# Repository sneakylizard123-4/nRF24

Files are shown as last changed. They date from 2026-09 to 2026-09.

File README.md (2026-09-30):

# nRF24 Breakout Board

A small 2.4GHz module based on the nRF24L01P+, with an SMA jack for an external
antenna, an on-board RFX2401C PA/LNA for extra range, and a breadboard friendly
SPI header. Runs from 3.3V or 5V off an on-board LDO.

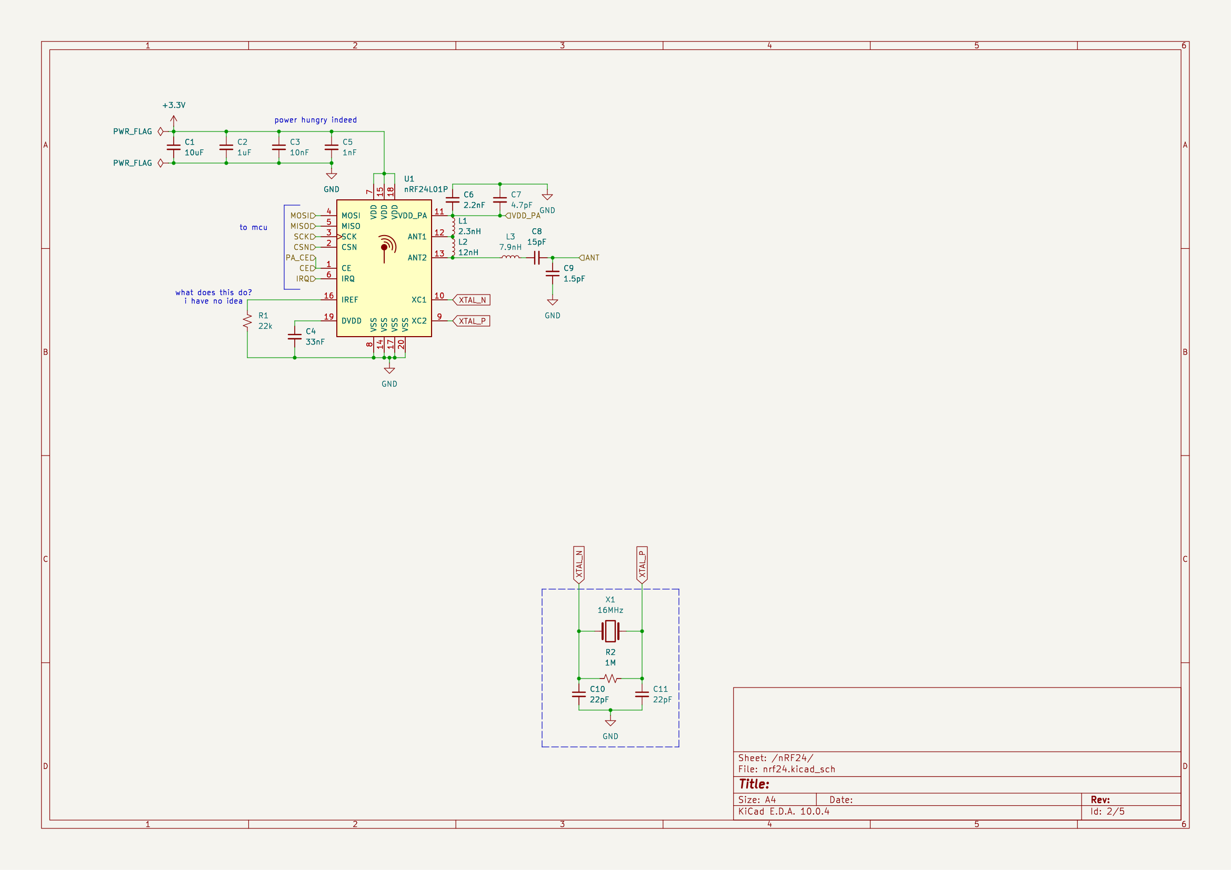
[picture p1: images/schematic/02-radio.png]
Radio sheet


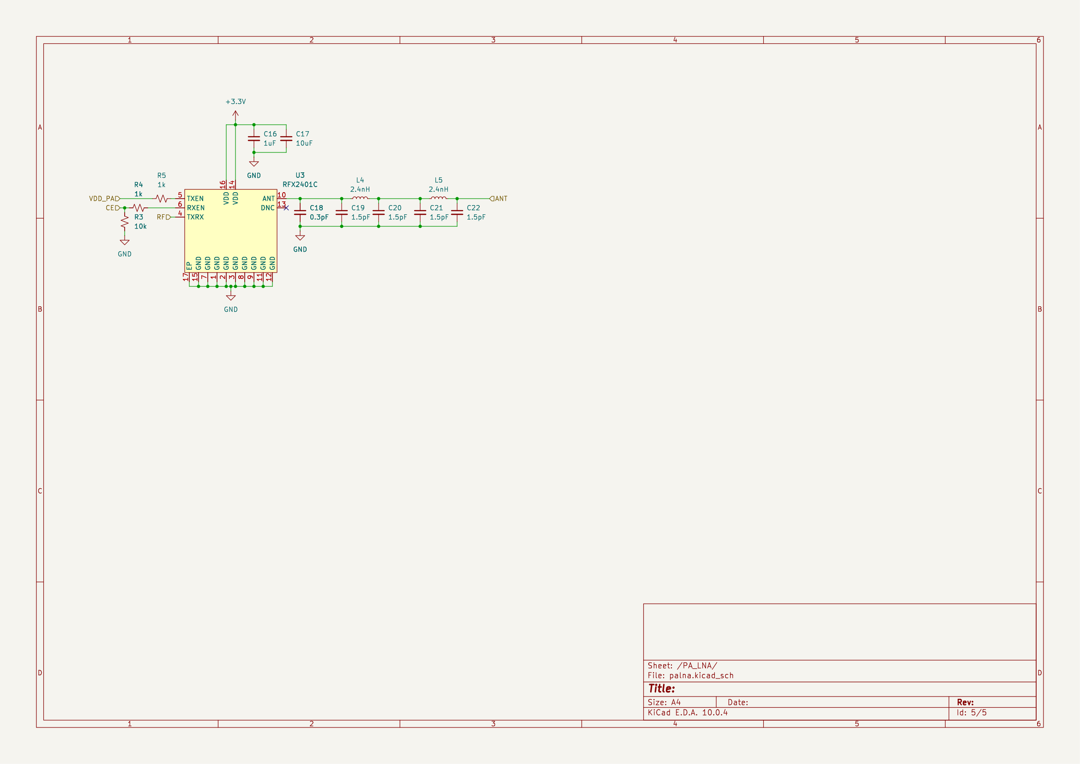
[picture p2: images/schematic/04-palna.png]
PA/LNA sheet


## Custom Features

- nRF24L01P+ 2.4GHz transceiver
- RFX2401C external PA/LNA for roughly +20dBm in TX and LNA gain in RX
- Discrete LC balun + harmonic filter
- LC match and DC block from the PA/LNA out to the SMA jack
- Right-angle SMA jack mounted on the board edge, for a real whip or panel antenna
- 16MHz crystal with matched load caps and bias resistor
- PA supply decoupled separately from the digital rail
- TLV75733 LDO: feed the header 3.3V or 5V and the board regulates itself
- 1x08 2.54mm header for drop-in SPI control from any MCU
- 2x M3 mounting holes

## How It Works

- The host MCU talks SPI over the header.
- The nRF24L01P+ differential PA outputs go through the LC balun and harmonic filter to become a single 50 ohm line which lands on the RFX2401C PA/LNA.
- The PA amplifies it and sends it through an LC match and DC block onto the SMA jack. In the other direction the LNA boosts received signals back down the same line.

The 16MHz crystal clocks the radio, a 1M bias resistor plus 22pF load caps set
the oscillator frequency.

### Power Tree

```mermaid
graph LR
  VIN[VIN: header pin 2, 3.3V or 5V]
  VIN --> LDO[U2 TLV75733]
  LDO --> R[+3.3V rail]
  R --> R1[U1 nRF24L01P+]
  R --> R2[U3 RFX2401C PA/LNA]
  R1 -->|ANT1/ANT2| Balun[LC balun + harmonic filter]
  Balun --> R2
  R2 --> Match[LC match + DC block]
  Match --> SMA[J2 antenna port]
```

## PCB Design

50.0 x 30.0 mm, 4-layer, 1.6mm thick, 5mm radius corners, on the JLCPCB
JLC04161H-7628 stackup. F.Cu carries the routing, In1.Cu is a solid ground
plane, In2.Cu is the +3.3V plane, and B.Cu has the leftover CE and VIN runs.

The PA/LNA sits on the RF line between the radio and the SMA, which hangs off the board edge.

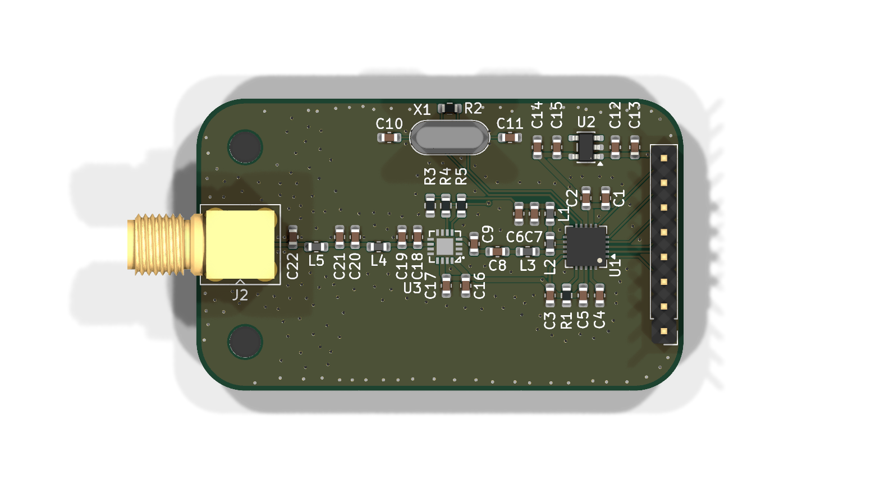
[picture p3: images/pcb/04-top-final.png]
Routed board


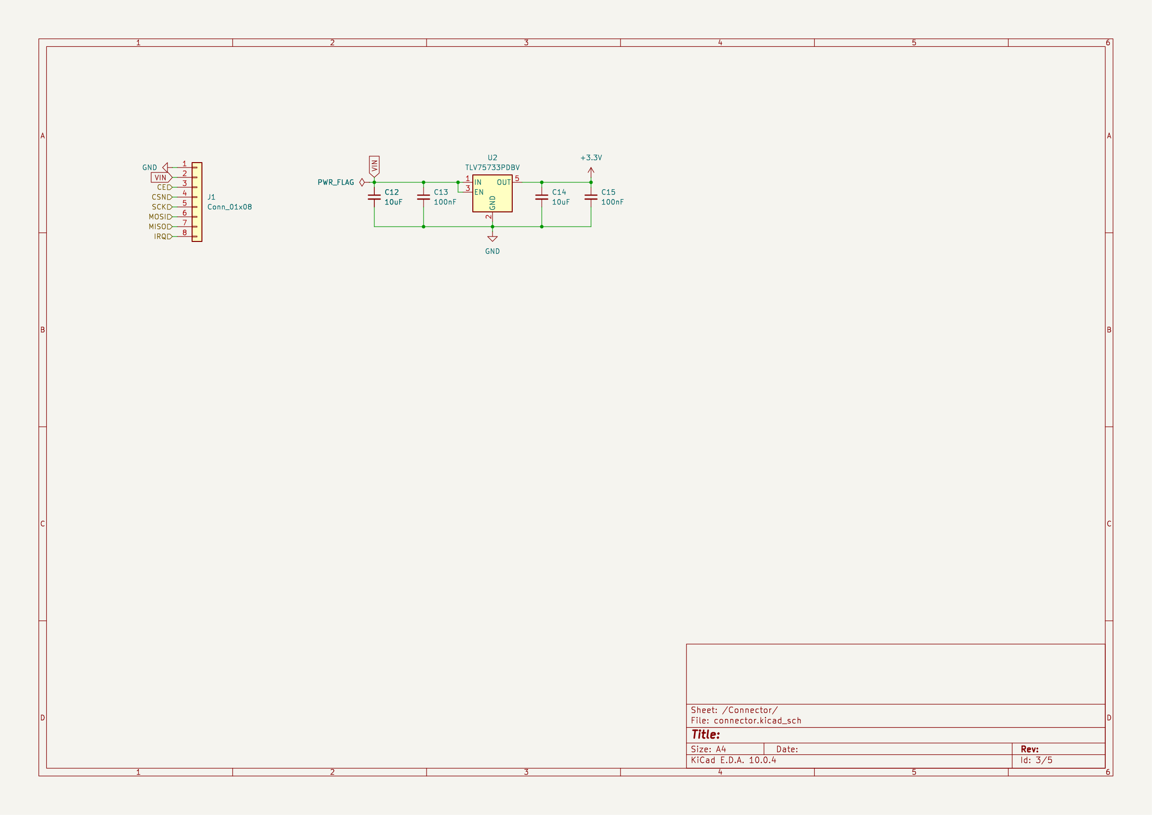
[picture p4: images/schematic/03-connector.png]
Connector sheet


## Usage

- The 3.3V rail comes from the on-board TLV75733, so the header VIN pin accepts 3.3V or 5V. The radio itself is a 3.3V part and is not 5V tolerant, which is what the LDO is there for.
- The radio talks SPI to your MCU. Neither the nRF24L01P+ nor the RFX2401C needs firmware of its own; you drive CE, CSN and IRQ from your own code.
- Fit an antenna on J2 before powering up. Do not run the PA into a transmitter with no load.

| Pin | Function |
|-----|---|
| 1 | GND |
| 2 | VIN (3.3-5V) |
| 3 | CE |
| 4 | CSN |
| 5 | SCK |
| 6 | MOSI |
| 7 | MISO |
| 8 | IRQ |

## BOM (Bill of Materials)

| Item | Cost |
|---|---|
| Components (per board) | $6.55 |
| Components (first order, MOQ rounded, 5 boards) | $20.12 |
| PCB (qty 5, 4-layer) | $8.10 ($1.62/board) |
| Controlled impedance (optional) | not quoted |
| **Total (5 boards, parts + boards)** | **$28.22** |
| Shipping (economy direct line, 8-13 business days) | $8.47 |

Quoted 2026-09-29 from the JLCPCB instant quote on the uploaded gerbers. The
detected board is 4 layer 30x50mm, qty 5. The $8.10 is a web-tier price made up of
a $8.00 promo plus $0.10 edge rounding; the JLCONE desktop tier came out at $2.10
for the same order. Shipping, tax, rush and controlled impedance are all outside
that number. Confirm the total at checkout, the promo may not persist.

See [BOM.csv](BOM.csv) for the full part list with LCSC part numbers, prices and
supplier links.

## Production

Not built yet. Board house is JLCPCB, 4-layer FR4 on the JLC04161H-7628
stackup, 1.6mm, HASL (lead-free), green, 50.0 x 30.0 mm inside a 100x100mm
panel, qty 5. That stackup puts 0.2104mm of prepreg between F.Cu and In1.Cu, so
the antenna trace on F.Cu references a ground plane 0.2104mm away, and In2.Cu
carries the +3.3V plane.

The board is hand-routed, no autorouter. The antenna-side net (`U3-ANT`) runs
as single-ended 0.4mm microstrip on F.Cu from the RFX2401C antenna pin to J2,
with the matching network (C19, L4, C20, C21, L5, C22) as an alternating LC
ladder along the way. The nRF24 differential PA outputs (`U1-ANT1`, `U1-ANT2`)
are also 0.4mm and stay paired until the balun. 221 through vias, mostly
stitching the top layer down to the In1.Cu ground plane.

The 0.4mm width is close but not exact. Over 0.2104mm of prepreg, 0.4mm works
out to 54 ohm and 0.46mm works out to 50, which stays inside the 45-55 ohm band
that JLCPCB's published +/-10% impedance tolerance allows on 4 layer and up. The
0.06mm change has not been made yet. See Known Issues.

## Repository Structure

```
|-- kicad/            # PCB source files (.kicad_sch / .kicad_pcb)
|   |-- parts/        # Project-local symbol / footprint / 3D libs
|   `-- production/   # Gerbers, drill files, netlist, position files
|-- images/           # Schematic exports and renders
|   |-- schematic/    # Per-sheet PNGs
|   |-- pcb/          # Layout progress shots
|   `-- screenshots/  # Build photos
|-- BOM.csv           # Bill of materials w/ links + total cost line
|-- JOURNAL.md        # Work journal
|-- LICENSE           # CERN OHL v2-P (hardware)
`-- LICENSE-MIT       # MIT (code)
```

## Known Issues

- Board is routed but unassembled and untested
- The antenna-side trace is 0.4mm over 0.2104mm of prepreg, which works out to 54 ohm rather than 50. 0.46mm is the correct width: 50 ohm nominal, inside the 45-55 ohm band JLCPCB publishes as its +/-10% tolerance on 4 layer. It is a 0.06mm change to 16.8mm of track and has not been made yet
- The F.Cu ground pour still runs right up to the antenna trace. On 4 layers that turns the trace into a coplanar waveguide and drops it below the calculated figure, so In1.Cu is not yet the only reference. The pour has to be cleared back from that run before the width number above means anything
- Two segments on the antenna nets are still 0.2mm rather than the surrounding width. 0.2mm is about 110 ohm on this stackup, so that is fine as pad fanout and a step discontinuity anywhere else. Worth checking which of the two it is
- All 221 vias are through vias, so every ground via punches an anti-pad in the In2.Cu +3.3V plane. Harmless at 3.3V, but it is a lot of voids in the rail
- The board render in PCB Design predates the move to 4 layers
- PA/LNA match uses tight-tolerance parts (0.3pF / 1.5pF / 2.4nH); the values may need tuning on the first real board
- TXEN/RXEN control of the RFX2401C is wired to VDD_PA and CE through 1k resistors - direction switching is a prototype hack, revisit if it misbehaves
- Two schematic parts are not orderable as drawn, so the footprints need editing before fabrication
  - L1 (2.3nH) and L3 (7.9nH) are drawn as 0603 but no 0603 part exists at those values; every 0603-numbered 2.3nH in the catalog is physically 0201. Both are specced as 0402, which lands inside the existing 0603 pads so no traces have to move
  - X1 was drawn as HC-52/U, which no supplier carries. The footprint is now an SMD 3225 4-pad and the BOM specced an SMD 3225 part to match, so this one is resolved. Worth knowing: the load caps are 22pF, which puts the network at roughly 13-15pF against a 12pF crystal, so it will run slightly low. The 22pF is the odd one out, not the crystal
- L2 (12nH) has a self-resonant frequency of 3GHz, uncomfortably close to the 2.4GHz operating point. 0603 inductors are marginal this high up; if the match does not settle, the fix is a larger inductor package, not a different value
- J2 is a generic 4-post THT SMA standing in for the Amphenol 901-143 the footprint is named after. The datasheet drawing for the substitute has not been checked against the footprint's ground-post pattern, so confirm the two agree before ordering boards
- U1 is a genuine Nordic nRF24L01P. The Si24R1 is pin-compatible and about 5x cheaper, but it is a different part and the radio registers and PA current draw both shift, so it sits in the BOM notes rather than in the design
- The U2 footprint value says TLV75733PDBV while the orderable part is the PDBVR tape-and-reel variant. Same die, different suffix, but the BOM carries the orderable one

## Credits & Inspiration

- [nRF24L01+ Product Spec](https://www.nordicsemi.com/products/nrf24l01) - reference balun/matching values and pinout
- RFX2401C symbol and footprint from the incutec-KiCad-Library (OpenRX FPGA project)

## License

Hardware (schematics, PCB layout, CAD and 3D models) is under
[CERN OHL v2-P](LICENSE), the permissive variant, because this is a personal
build and not a product. If boards are ever sold, relicense to CERN-OHL-S.

    SPDX-License-Identifier: CERN-OHL-P-2.0

Any code in this repository (build scripts, and any firmware added later) is
licensed under the MIT License.

    SPDX-License-Identifier: MIT

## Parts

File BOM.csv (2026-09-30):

Designator | Footprint | Quantity | Value | LCSC Part # | MPN | MOQ | Unit Price | Total Cost | Amount | Supplier Link | Notes
C1, C12, C14, C17 | Capacitor_SMD:C_0603_1608Metric | 4 | 10uF | C19702 | CL10A106KP8NNNC | 20 | $0.0322 | $0.6440 | 20 | https://www.lcsc.com/product-detail/C19702.html | 10uF 50V X5R
C10, C11 | Capacitor_SMD:C_0603_1608Metric | 2 | 22pF | C376775 | TCC0603COG220J500CT | 100 | $0.0049 | $0.4900 | 100 | https://www.lcsc.com/product-detail/C376775.html | 50V C0G
C13, C15 | Capacitor_SMD:C_0603_1608Metric | 2 | 100nF | C282519 | TCC0603X7R104K500CT | 20 | $0.0094 | $0.1880 | 20 | https://www.lcsc.com/product-detail/C282519.html | 50V X7R
C2, C16 | Capacitor_SMD:C_0603_1608Metric | 2 | 1uF | C20070307 | CGA0603X5R105K100JT | 100 | $0.0084 | $0.8400 | 100 | https://www.lcsc.com/product-detail/C20070307.html | 10V X5R
C18 | Capacitor_SMD:C_0603_1608Metric | 1 | 0.3pF | C53514 | 0603CG0R3C500NT | 100 | $0.0063 | $0.6300 | 100 | https://www.lcsc.com/product-detail/C53514.html | 50V C0G
C9, C19, C20, C21, C22 | Capacitor_SMD:C_0603_1608Metric | 5 | 1.5pF | C376772 | TCC0603COG1R5C500CT | 100 | $0.0047 | $0.4700 | 100 | https://www.lcsc.com/product-detail/C376772.html | 50V C0G
C3 | Capacitor_SMD:C_0603_1608Metric | 1 | 10nF | C163179 | 0603B103K250CT | 10 | $0.0048 | $0.0480 | 10 | https://www.lcsc.com/product-detail/C163179.html | 25V X7R
C4 | Capacitor_SMD:C_0603_1608Metric | 1 | 33nF | C696862 | TCC0603X7R333M500CT | 100 | $0.0050 | $0.5000 | 100 | https://www.lcsc.com/product-detail/C696862.html | 50V X7R
C5 | Capacitor_SMD:C_0603_1608Metric | 1 | 1nF | C106246 | CC0603JRNPO9BN102 | 50 | $0.0054 | $0.2700 | 50 | https://www.lcsc.com/product-detail/C106246.html | 50V NP0
C6 | Capacitor_SMD:C_0603_1608Metric | 1 | 2.2nF | C374074 | TCC0603X7R222K500CT | 100 | $0.0044 | $0.4400 | 100 | https://www.lcsc.com/product-detail/C374074.html | 50V X7R
C7 | Capacitor_SMD:C_0603_1608Metric | 1 | 4.7pF | C282506 | TCC0603COG4R7C500CT | 10 | $0.0022 | $0.0220 | 10 | https://www.lcsc.com/product-detail/C282506.html | 50V C0G
C8 | Capacitor_SMD:C_0603_1608Metric | 1 | 15pF | C107037 | CC0603JRNPO9BN150 | 100 | $0.0033 | $0.3300 | 100 | https://www.lcsc.com/product-detail/C107037.html | 50V NP0
J1 | Connector_PinHeader_2.54mm:PinHeader_1x08_P2.54mm_Vertical | 1 | Conn_01x08 | C124381 | B-2100S08P-A110 | 5 | $0.0796 | $0.3980 | 5 | https://www.lcsc.com/product-detail/C124381.html | THT vertical, matches footprint
J2 | Connector_Coaxial:SMA_Amphenol_901-143_Horizontal | 1 | Conn_Coaxial | C496549 | BWSMA-KE-Z001 | 1 | $0.4053 | $0.4053 | 1 | https://www.lcsc.com/product-detail/C496549.html | SUBSTITUTE: generic 4-post THT SMA right-angle. VERIFY ground-post pattern vs datasheet before ordering
L1 | Inductor_SMD:L_0402_1005Metric | 1 | 2.3nH | C3910891 | LQG15WZ2N3B02D | 5 | $0.1305 | $0.6525 | 5 | https://www.lcsc.com/product-detail/C3910891.html | SUBSTITUTE: 2.3nH does not exist in 0603 (all 0603-numbered 2.3nH are 0201). 0402 land is 1.56mm span vs 2.45mm for 0603, so it fits the existing pads with no re-route. SRF 7GHz
L2 | Inductor_SMD:L_0603_1608Metric | 1 | 12nH | C55067212 | LQG1608HS12NJT | 50 | $0.0086 | $0.4300 | 50 | https://www.lcsc.com/product-detail/C55067212.html | CAUTION: SRF is 3GHz, close to the 2.4GHz operating point
L3 | Inductor_SMD:L_0402_1005Metric | 1 | 7.9nH | C412360 | LQW15AN7N9C10D | 10 | $0.0583 | $0.5830 | 10 | https://www.lcsc.com/product-detail/C412360.html | SUBSTITUTE: 7.9nH does not exist in 0603. 0402 land is 1.56mm span vs 2.45mm for 0603, so it fits the existing pads with no re-route
L4, L5 | Inductor_SMD:L_0603_1608Metric | 2 | 2.4nH | C55067198 | LQG1608HS2N4ST | 50 | $0.0086 | $0.4300 | 50 | https://www.lcsc.com/product-detail/C55067198.html | SRF 6GHz
R1 | Resistor_SMD:R_0603_1608Metric | 1 | 22k | C31850 | 0603WAF2202T5E | 100 | $0.0042 | $0.4200 | 100 | https://www.lcsc.com/product-detail/C31850.html | 1% 100mW
R2 | Resistor_SMD:R_0603_1608Metric | 1 | 1M | C22935 | 0603WAF1004T5E | 100 | $0.0020 | $0.2000 | 100 | https://www.lcsc.com/product-detail/C22935.html | 1% 100mW
R3 | Resistor_SMD:R_0603_1608Metric | 1 | 10k | C98220 | RC0603FR-0710KL | 100 | $0.0035 | $0.3500 | 100 | https://www.lcsc.com/product-detail/C98220.html | 1% 100mW
R4, R5 | Resistor_SMD:R_0603_1608Metric | 2 | 1k | C21190 | 0603WAF1001T5E | 100 | $0.0026 | $0.2600 | 100 | https://www.lcsc.com/product-detail/C21190.html | 1% 100mW
U1 | Package_DFN_QFN:QFN-20-1EP_4x4mm_P0.5mm_EP2.5x2.5mm | 1 | nRF24L01P | C8791 | NRF24L01P-R | 1 | $4.3494 | $4.3494 | 1 | https://www.lcsc.com/product-detail/C8791.html | Nordic. Cheaper pin-compatible drop-in: Si24R1 C14436 (https://www.lcsc.com/product-detail/C14436.html) at $0.8720, needs firmware revalidation
U2 | Package_TO_SOT_SMD:SOT-23-5 | 1 | TLV75733PDBV | C485517 | TLV75733PDBVR | 5 | $0.2010 | $1.0050 | 5 | https://www.lcsc.com/product-detail/C485517.html | 3.3V LDO. Footprint value says PDBV (tape&reel suffix) but the orderable part is PDBVR
U3 | RFX2401C:QFN-16_L3.0-W3.0-P0.50-BL-EP1.7 | 1 | RFX2401C | C19213 | RFX2401C | 5 | $0.9590 | $4.7950 | 5 | https://www.lcsc.com/product-detail/C19213.html | Skyworks PA/LNA, 2.4-2.5GHz, 22dBm out, 2-3.6V. This part was missing from this BOM entirely, so the front end the whole board exists for was never costed. Footprint is the project-local one under kicad/parts/libs/RFX2401C.pretty, which does not match the LCSC package name QFN-16-EP(3x3). Avoid the cheaper Tokmas clone C55019287, it has no published specs
X1 | Crystal:Crystal_SMD_3225-4Pin_3.2x2.5mm | 1 | 16MHz | C12668 | X322516MOB4SI | 10 | $0.0969 | $0.9690 | 10 | https://www.lcsc.com/product-detail/C12668.html | FOOTPRINT FIX: the board has carried Crystal_SMD_3225-4Pin_3.2x2.5mm (4-pad, pads 2 and 4 to GND) since the 26th, so the old HC-49S 2-pin through-hole part could never have been assembled onto it. This is the SMD 3225 equivalent. CL 12pF is the nRF24L01P typ, ESR 50ohm against a 100ohm ceiling, +/-10ppm against the +/-60ppm allowed. CAVEAT: C10/C11 are 22pF, so the network is 11pF plus stray, about 13-15pF, which is above this crystal's 12pF rating and will run it slightly low. Still inside the 8-16pF spec window, but if it drifts the load caps are wrong, not the crystal
PCB | (board outline 50.0 x 30.0 mm) | 5 | 4-layer FR4 1.6mm HASL Green JLC04161H-7628 30x50mm |  |  | 1 | $1.62 | $8.10 | 5 | https://jlcpcb.com/quote | QUOTED 2026-09-29 from JLCPCB instant quote on the uploaded gerbers: detected 4 layer 30x50mm, qty 5. $8.10 web total = $8.00 special offer + $0.10 edge rounding. JLCONE desktop tier would be $2.10. Not included: shipping, tax, rush (2-3 day is +$66.20), controlled impedance. Confirm price at checkout, the $8.00 is a promo
PCB IMPEDANCE CONTROL |  | 5 | Controlled impedance +/-10% (JLCPCB high-precision option) |  |  |  | not quoted | not quoted | 5 | https://jlcpcb.com/help/article/pcb-capabilities-controlled-impedance | NOT INCLUDED in the $8.10 above, the instant quote returned impedanceFlag=no. JLCPCB did not expose the surcharge to the instant quote so the cost is unknown until checkout. JLCPCB publishes +/-10% impedance tolerance on 4 layer and up, which is 45-55 ohm on this 50 ohm run, so order it if the antenna match has to be held tighter than that
STENCIL |  | 0 | 100x100mm stainless stencil - NOT being ordered |  |  |  |  | $0.00 | 0 | https://jlcpcb.com/quote | Optional. Add only if you want JLCPCB to solder U1 (QFN-20) and U2 (SOT-23-5); otherwise hand-solder and skip this line
TOTAL |  |  | Components: $20.12 |  |  |  |  |  |  |  | Per-board component cost: $6.55
TOTAL |  |  | PCBs: $8.10 |  |  |  |  |  |  |  | Board qty 5 per-board $1.62
TOTAL |  |  | Shipping: $8.47 |  |  |  |  |  |  |  | Economy direct line (JLCPCB HKTHZXR-RMB), 8-13 business days, offered under the $59 order limit. Cheapest option that satisfies the Forge shipping rule in Forge.md (global standard direct line, 4PX, or cheapest). DHL Express DDP was $30.86, UPS $27.06, FedEx $32.69, all express air and not reimbursable. 4PX was not offered for this destination
TOTAL |  |  | GRAND TOTAL: $28.22 |  |  |  |  |  |  |  | Parts $20.12 + PCBs $8.10. Excludes shipping, tax, controlled impedance and the optional SMT assembly. H1 and H2 are mounting holes machined by the fab, there is no part to buy for them

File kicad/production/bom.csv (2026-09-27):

Designator | Footprint | Quantity | Value | LCSC Part #
C1, C12, C14, C17 | 0603 | 4 | 10uF
C10, C11 | 0603 | 2 | 22pF
C13, C15 | 0603 | 2 | 100nF
C16, C2 | 0603 | 2 | 1uF
C18 | 0603 | 1 | 0.3pF
C19, C20, C21, C22, C9 | 0603 | 5 | 1.5pF
C3 | 0603 | 1 | 10nF
C4 | 0603 | 1 | 33nF
C5 | 0603 | 1 | 1nF
C6 | 0603 | 1 | 2.2nF
C7 | 0603 | 1 | 4.7pF
C8 | 0603 | 1 | 15pF
J1 | PinHeader_1x08_P2.54mm_Vertical | 1 | Conn_01x08
J2 | SMA_Amphenol_901-143_Horizontal | 1 | Conn_Coaxial
L1 | 0603 | 1 | 2.3nH
L2 | 0603 | 1 | 12nH
L3 | 0603 | 1 | 7.9nH
L4, L5 | 0603 | 2 | 2.4nH
R1 | 0603 | 1 | 22k
R2 | 0603 | 1 | 1M
R3 | 0603 | 1 | 10k
R4, R5 | 0603 | 2 | 1k
U1 | QFN-20-1EP_4x4mm_P0.5mm_EP2.5x2.5mm | 1 | nRF24L01P
U2 | SOT-23-5 | 1 | TLV75733PDBV
U3 | QFN-16_L3.0-W3.0-P0.50-BL-EP1.7 | 1 | RFX2401C | C19213
X1 | Crystal_SMD_3225-4Pin_3.2x2.5mm | 1 | 16MHz

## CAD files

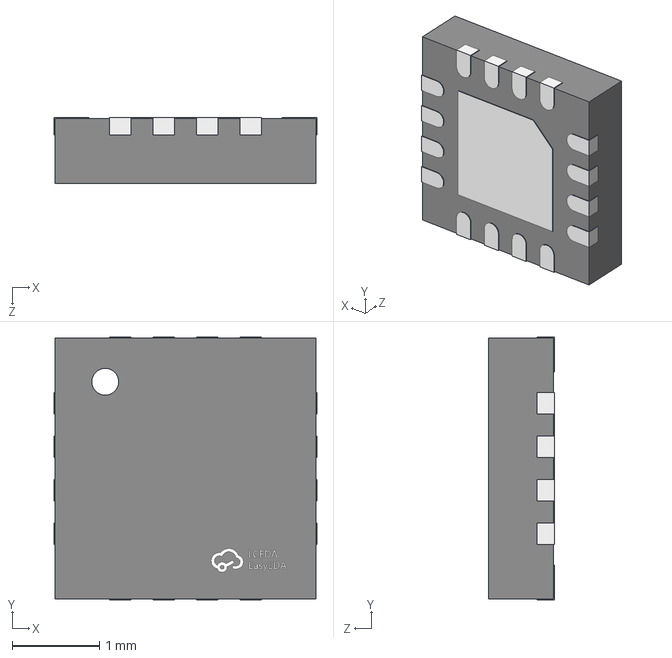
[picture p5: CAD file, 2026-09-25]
kicad/parts/3dmodel/RFX2401C.step
3.02 x 3.02 x 0.76 mm

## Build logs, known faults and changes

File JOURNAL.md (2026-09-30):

---
title: nRF24 Breakout Board
author: sneakylizard123-4
description: Discrete nRF24L01P+ 2.4GHz transceiver breakout with a hand-routed LC balun and SMA antenna port, driven over SPI from any 3.3V MCU.
created_at: 2026-09-20
---

# September 20: Schematic done, board started, ERC clean

## What I did:

- Set up the KiCad project: root sheet plus two sub-sheets (radio + connector)
- Placed the nRF24L01P+ and built the RF front end by hand: LC balun and harmonic filter out to an SMA jack
- Added the 16MHz crystal with load caps and bias resistor
- Wired VDD_PA filter so the PA supply and balun share cleanly
- Ran the interface off one 1x08 2.54mm header: GND, VCC, CE, CSN, SCK, MOSI, MISO, IRQ
- 1x08 header is more breadboard friendly than the standard 2x4 header
- Ran ERC - no violations
- Started the PCB: 20 footprints placed manually on a board, routing not started
- Exported schematic PNGs into images/schematic/

## Why:

- I want a real nRF24 board (with a PA/LNA??) instead of a module, so the RF path is fully mine to tune and I get a proper SMA port instead of just a pcb antenna
- The PA outputs (ANT1/ANT2) are differential; they need a balun to reach a 50 ohm single-ended antenna, and the same LC network stops harmonics
- 2/4 layer (undecided), cheap fab because this is the first spin and the RF budget is modest

## Screenshots:

Radio sheet

Connector sheet

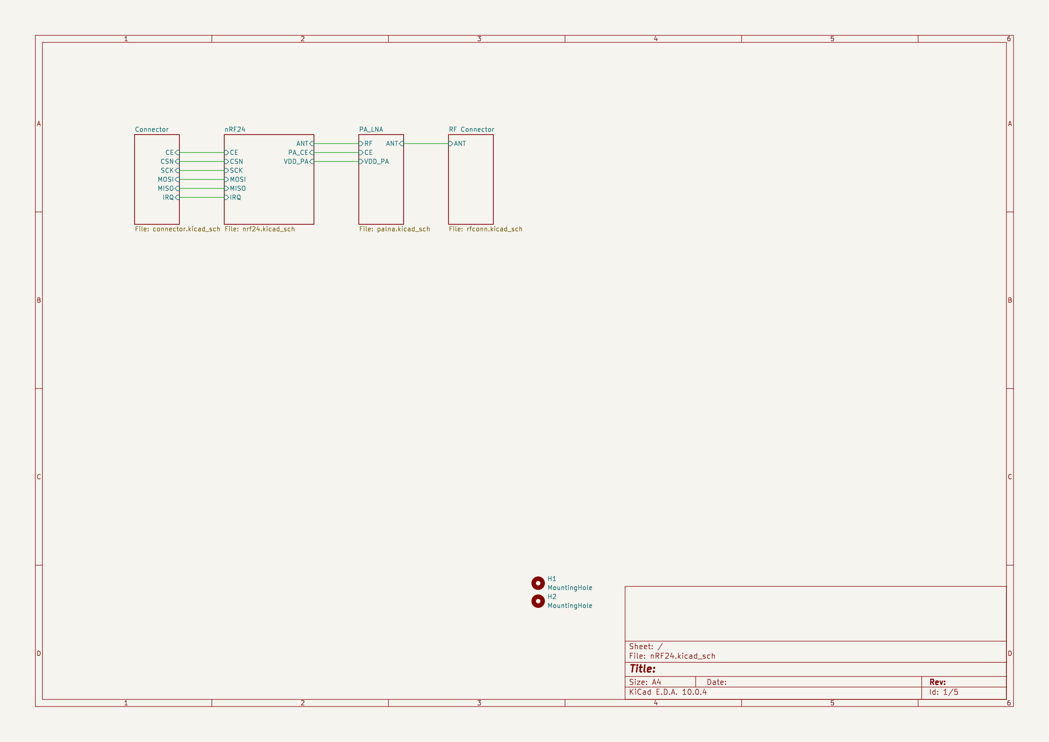
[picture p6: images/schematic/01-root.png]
Root sheet


**Total time spent: 1 hour**

# September 21: rf connector sheet

## What I did:

- Made a new sheet for the sma connector and balun
- Added a 3.3v regulator

## Why:

- Planning on adding a PA/LNA to the nRF24 to boost its range
- 3.3v regulator so that it can be powered from 5v mcus too hopefully

## Screenshots:

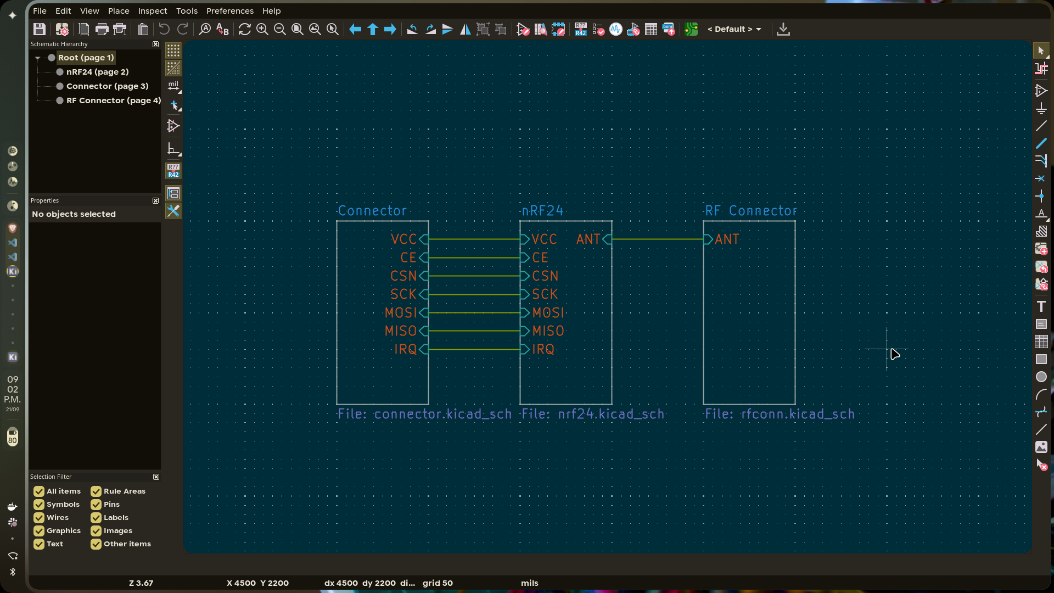
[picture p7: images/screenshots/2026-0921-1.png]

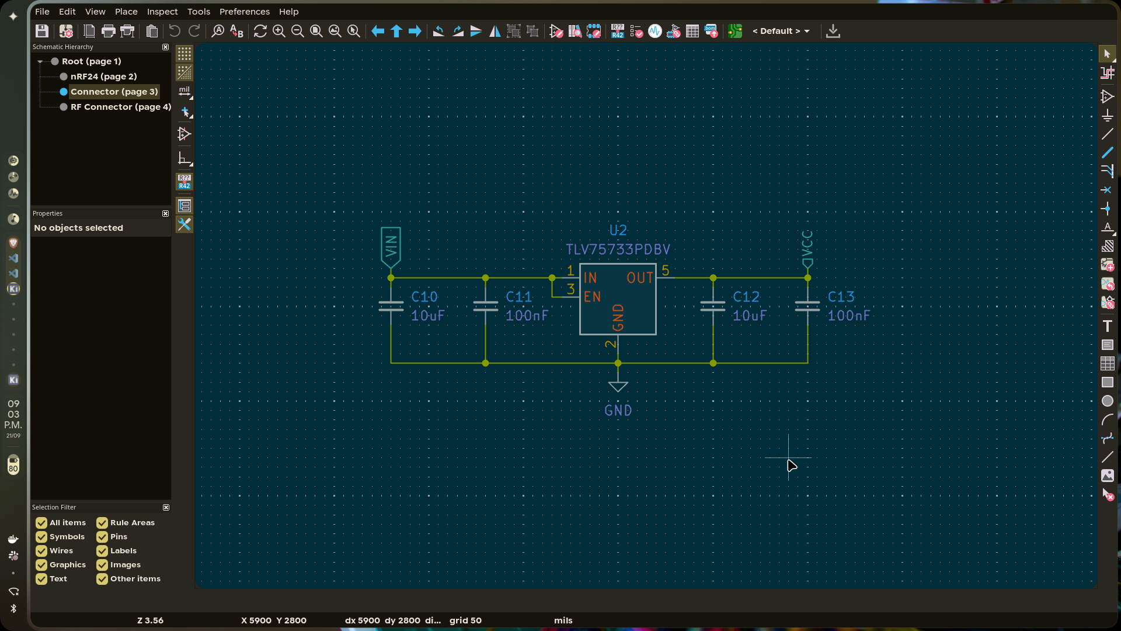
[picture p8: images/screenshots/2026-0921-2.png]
ldo


**Total time spent: 1 hour**

# September 24: PA/LNA in, board started

## What I did:

- Grabbed the RFX2401C symbol and footprint and dropped it on a new PA_LNA sheet (U3)
- Wired the nRF24 balun output onto the PA input (TXRX) and the antenna pin out to an LC match + DC block
- Control pins pulled through 1k resistors
- Gave the SMA connector its own RF connector sheet so the RF chain is easy to read
- Put the header and a TLV75733 LDO on the connector sheet so 5V hosts can feed the board
- Added 2x M3 mounting holes to the root sheets
- Grew the board from ~34x29 to 53.5x34mm, 1-layer to 2-layer, to fit the PA/LNA and its RF line
- Placed all 40 footprints, starting the board for the routing pass

## Why:

- The nRF24L01P+ internal PA only does about +0dBm
- RFX2401C adds a real PA (~+20dBm) plus an LNA, for improved range
- The radio's PA is differential and the PA/LNA is single-ended, so the balun has to hand the RFX2401C a clean 50 ohm line, then match the PA side back to the antenna
- Registering the parts project-local (kicad/parts/) so the schematic builds without depending on a global library

## Screenshots:

PA/LNA sheet

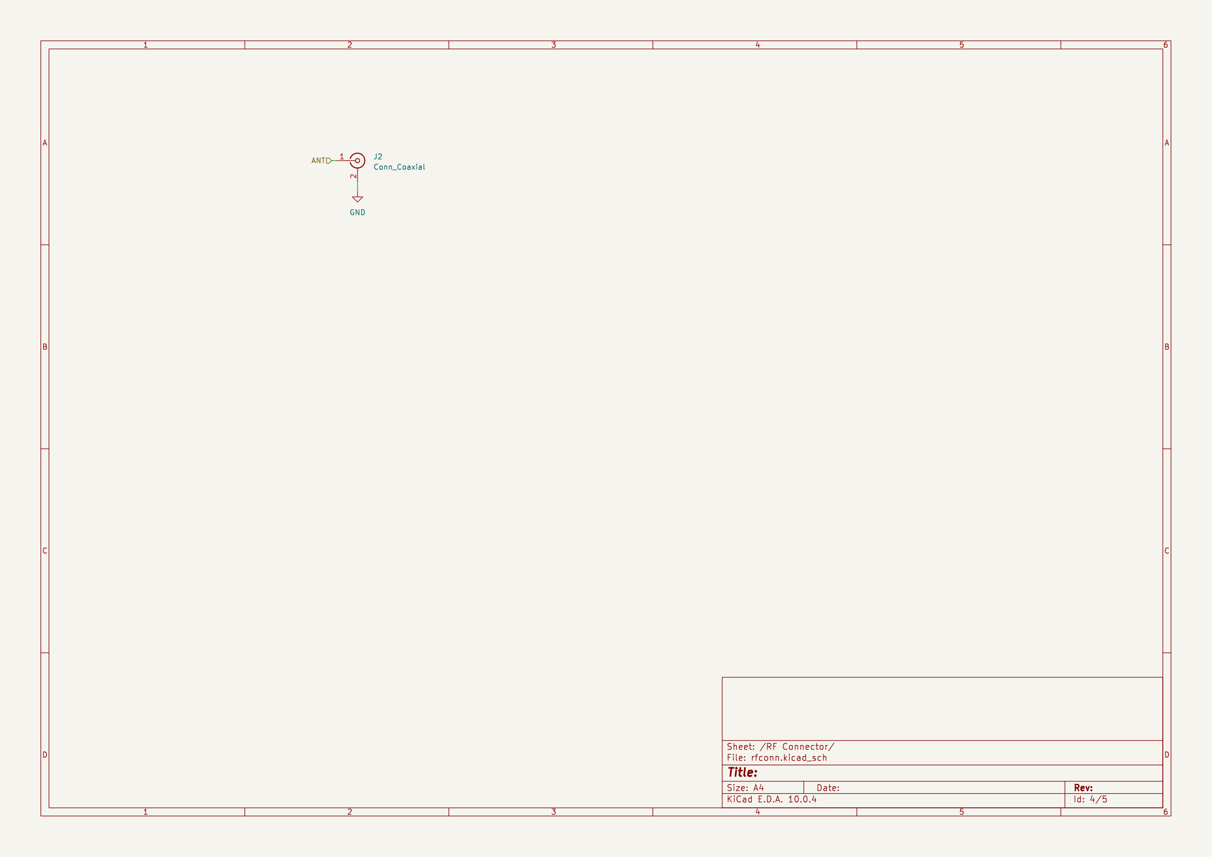
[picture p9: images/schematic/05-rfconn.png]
RF connector sheet


**Total time spent: 1 hour**

# September 24: Routed the board

## What I did:

- Started routing at 21:09 off the 40-footprint placement
- Routed the first signals by hand: SPI, CE, IRQ, the crystal pair, then the power nets
- Tried a bulk auto-route pass through freerouting (DSN export) twice - both times it buried the RF traces under vias, so I undid it and did the whole thing by hand
- Left the RF chain (balun to PA to SMA) as the cleanest, shortest run on top
- Finished at 21:50: 126 tracks and 219 vias, mostly via fan-out for the ground return on the 2-layer stack

## Why:

- The 2.4GHz path is the whole point of this board, so it had to be a deliberate hand route, not whatever a bulk router churns out
- 2-layer boards only have the one solid ground return, so I leaned on stitched vias to keep GND continuous under the RF line instead of skimping
- The board grew to fit a proper layout: 53.5x34mm so the SMA hangs off the edge and the header stays breadboard friendly

## Screenshots:

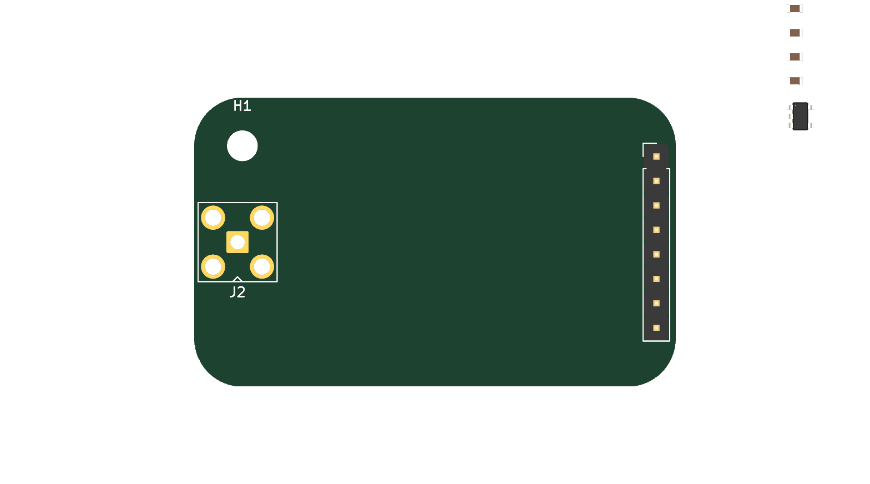
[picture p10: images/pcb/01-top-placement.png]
Footprints placed, no traces (20:08)


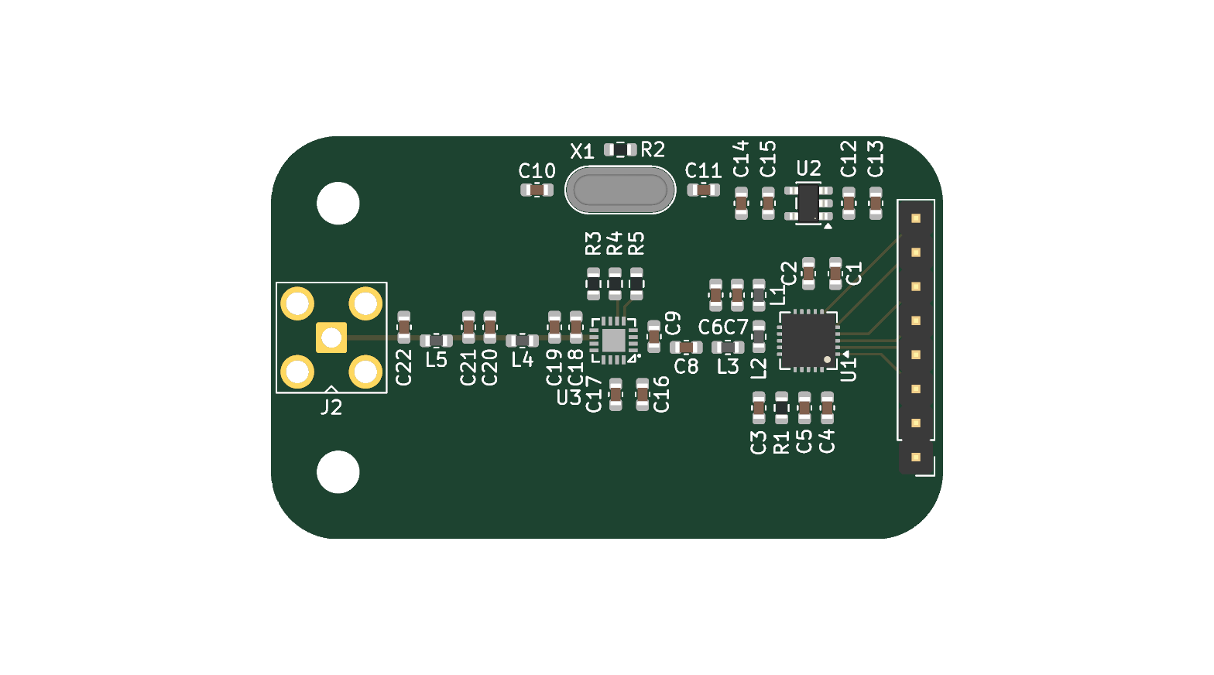
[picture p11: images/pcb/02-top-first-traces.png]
First traces going down (21:15)


Final board top: 126 tracks (21:50)

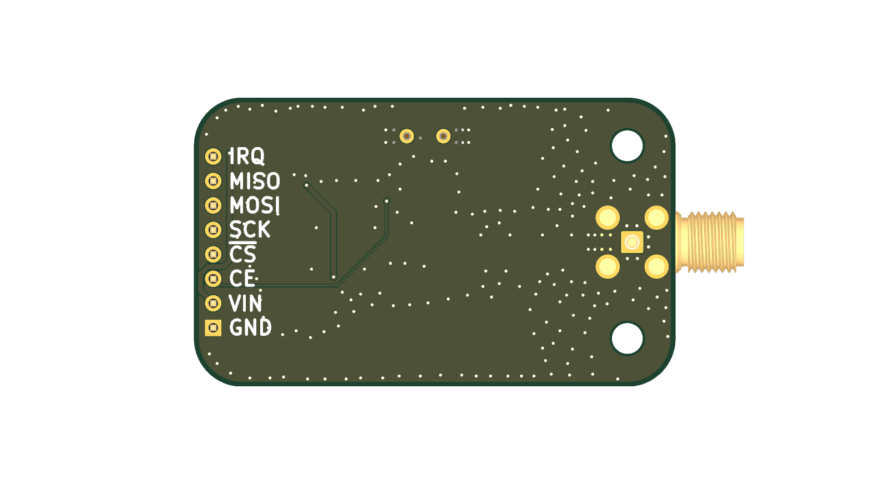
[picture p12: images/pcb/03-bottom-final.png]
Final board bottom: ground via web


**Total time spent: 2 hours**

# September 25: RFX2401C symbol, footprint and 3D model

## What I did:

- Brought the RFX2401C in properly instead of borrowing a generic symbol: wrote the project-local symbol (RFX2401C.kicad_sym) and a QFN-16 footprint with a 3.0x3.0mm body on a 0.50mm pitch
- Generated the 3D model from the package drawing (RFX2401C.step) so the board actually looks like the part instead of a grey box
- Rebuilt the PA_LNA sheet around the real pinout, which is where most of the day went
- Grew the placement on the board to match, then re-checked the ground return under the new part

## Why:

- I had been treating the RFX2401C as a black box with two RF pins. With a real symbol I could actually read the enable and mode pins and wire them instead of guessing
- The exposed pad matters here. It is the ground return for the whole front end, so it had to be a real thermal pad in the footprint rather than left off
- The 3D model is not decoration, it is how I catch a part hanging off the edge of the board before ordering

## Screenshots:

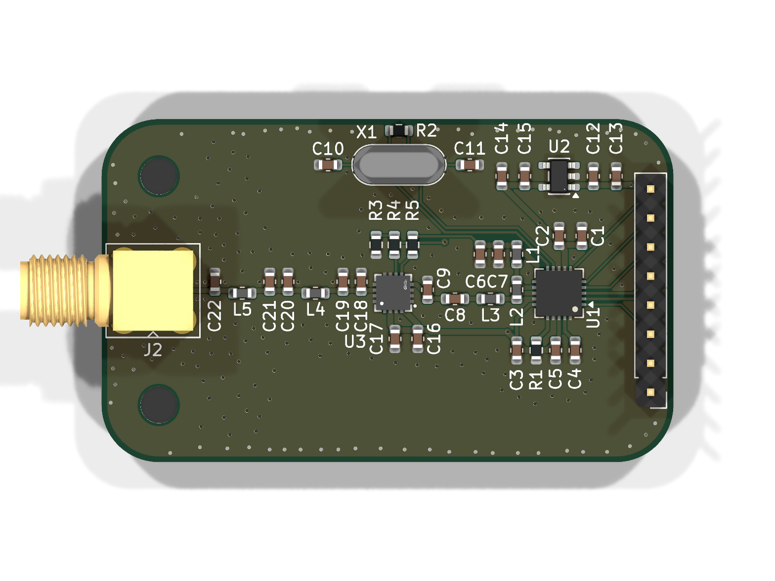
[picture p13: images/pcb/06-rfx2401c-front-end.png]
The RFX2401C placed on the 2-layer board, rendered from the STEP model


**Total time spent: 1 hour**

# September 26: BOM, licenses, and a lot of checking

## What I did:

- Built BOM.csv off the production bom
- Added LICENSE (CERN OHL v2-P) and LICENSE-MIT
- Fixed the board size in the README
- Measured the routed antenna trace: U3-ANT is 0.4mm single-ended over solid ground on 1.6mm FR4, which works out to about 122 ohm rather than 50
- Worked out that there is no trace width that fixes it on 2 layers at 1.6mm. 50 ohm needs 3.3mm, but the shunt caps are 0603 on a 1.575mm pitch, so a 3.3mm trace swallows them and the C-L-C-L-C ladder stops being a ladder
- A 4-layer stack with 0.21mm prepreg hits 50 ohm at 0.46mm, so the width I drew is about right for 4 layers and badly wrong for the 2-layer board it is on
- L1 (2.3nH) and L3 (7.9nH) have no 0603 part at those values. Every 0603-numbered 2.3nH in the catalog is physically 0201, which will not sit on a 0603 pad. Swapped to 0402, small enough to land inside the existing pads
- L2 (12nH) has a self-resonant frequency of 3GHz, uncomfortably close to running at 2.4GHz
- Added a .gitignore, and untracked kicad/.history. It was committed as a gitlink with no .gitmodules entry, so cloning the repo errored out on submodule status

## Why:

- Forge wants a supplier link on every line item and a total
- CERN OHL v2-P because this is a personal 5-board build, not a product. Relicense to -S if boards are ever sold
- The board size was wrong because I wrote 53.5x34mm from memory instead of measuring the outline. Same for the trace impedance, and the first number I wrote for that was wrong too, in the other direction. Both are the kind of thing you only catch by measuring, so both are written down now

## Screenshots:



**Total time spent: 1 hour**

# September 26: Back to 4 layers

## What I did:

- Switched the stackup to JLCPCB's JLC04161H-7628: 4 layers, 0.2104mm of prepreg down to In1.Cu, 1.065mm core, 1.6062mm total
- Put a solid GND plane on In1.Cu and the +3.3V plane on In2.Cu. F.Cu keeps all the routing, B.Cu keeps the 10 CE and VIN runs
- Left the 221 through vias alone. They already tie F.Cu down to ground, and now that there is a ground plane 0.245mm under the antenna that is exactly what I wanted
- Recomputed the antenna trace against the real prepreg instead of an assumed 1.6mm of solid FR4: 0.4mm is 54 ohm, 0.46mm is 50 ohm and holds 46-54 ohm across the prepreg and er spread JLC holds
- Rewrote the README for the 4-layer stackup and pulled the stale 2-layer and 70 ohm figures out of it

## Why:

- 2 layers at 1.6mm cannot do 50 ohm here. 50 ohm needs 3.3mm of trace, the shunt caps are 0603 on a 1.575mm pitch, so anything that wide stops being a matching ladder
- A ground plane 0.2104mm under the trace is what makes the impedance a number I can calculate instead of guess at

## Still to do:

- Widen the antenna run from 0.4mm to 0.46mm. It is a 0.06mm change to 16.8mm of track
- Clear the F.Cu ground pour back off the antenna run. Until that is done the trace is a coplanar waveguide, not a microstrip, and the 50 ohm above is not what the board will actually do
- Chase up the two 0.2mm segments still sitting on the antenna nets
- Get a real 4-layer quote from JLCPCB. The $10.00 in the README was a 2-layer estimate and is now marked pending rather than guessed at. Done on the 29th, it came out at $8.10

## Screenshots:

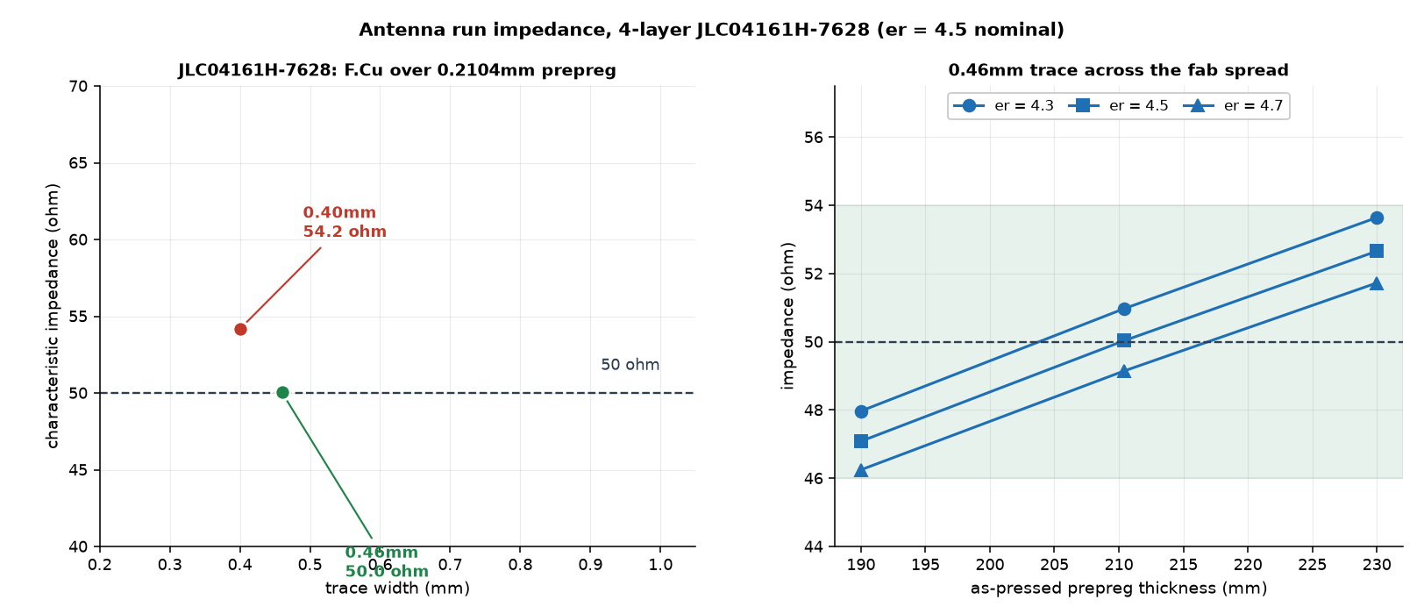
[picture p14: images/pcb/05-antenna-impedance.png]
Antenna trace impedance on the new stackup, and its tolerance across the fab spread


**Total time spent: 1 hour**

# September 26: Fabrication package and the crystal footprint

## What I did:

- Exported the full fabrication package into kicad/production/
- Changed the crystal footprint from HC-52/U vertical to an SMD 3225 4-pad (Crystal_SMD_3225-4Pin_3.2x2.5mm) across the schematic and the board
- Grew the board outline to the 50.0 x 30.0mm

## Why:

- HC-52/U is not a part anyone stocks. Worth swapping for something orderable before ordering rather than after
- Going to a 4-pad SMD part is a bigger change than the through-hole swap I had planned, because the extra two pads have to be tied to ground rather than left floating
- Exporting the whole package in one go is how you find out that a footprint is broken. Anything missing

## Screenshots:

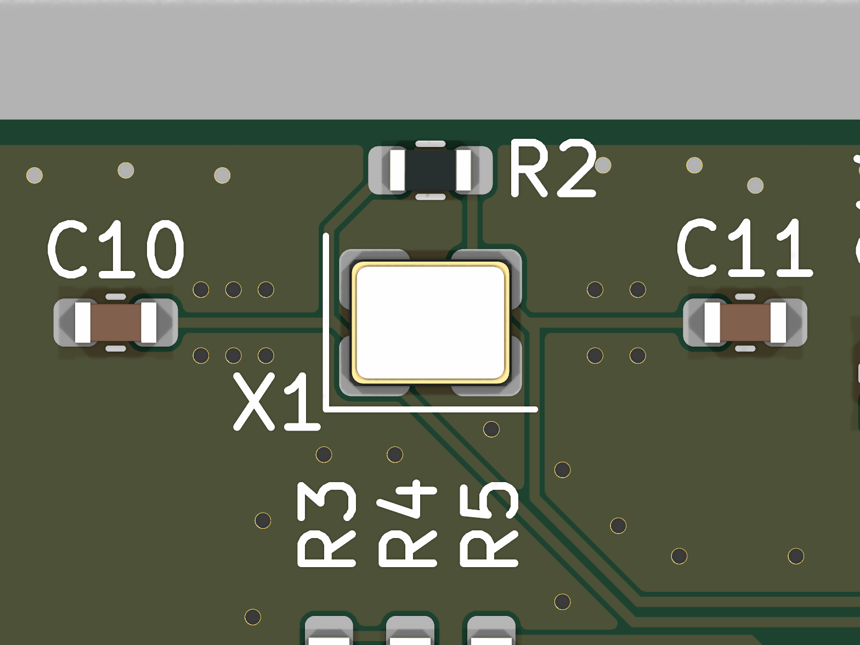
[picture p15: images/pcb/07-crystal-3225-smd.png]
X1 after the swap, the 3225 SMD crystal at 3.2x2.5mm with the two load caps around it


**Total time spent: 1 hour**

# September 29: Real 4-layer quote, and what the impedance tolerance actually is

## What I did:

- Uploaded kicad/production/nRF24.zip to the JLCPCB instant quote instead of keeping the 2-layer estimate
- Got $8.10 for 5 boards of 4 layer 30x50mm: $8.00 of that is a special offer and $0.10 is edge rounding. The JLCONE desktop tier came out at $2.10 for the same order
- Checked what JLCPCB actually holds the trace width to, and it is +/-10% So the 0.46mm run lands in 45-55 ohm
- Added controlled impedance to the BOM as a line with an unknown cost, because the instant quote returned impedanceFlag=no and would not show the surcharge

## Why:

- I nearly wrote +/-20% into the BOM.
- Controlled impedance is worth a line in the BOM even at an unknown price because it is quite important for board function

## Screenshots:

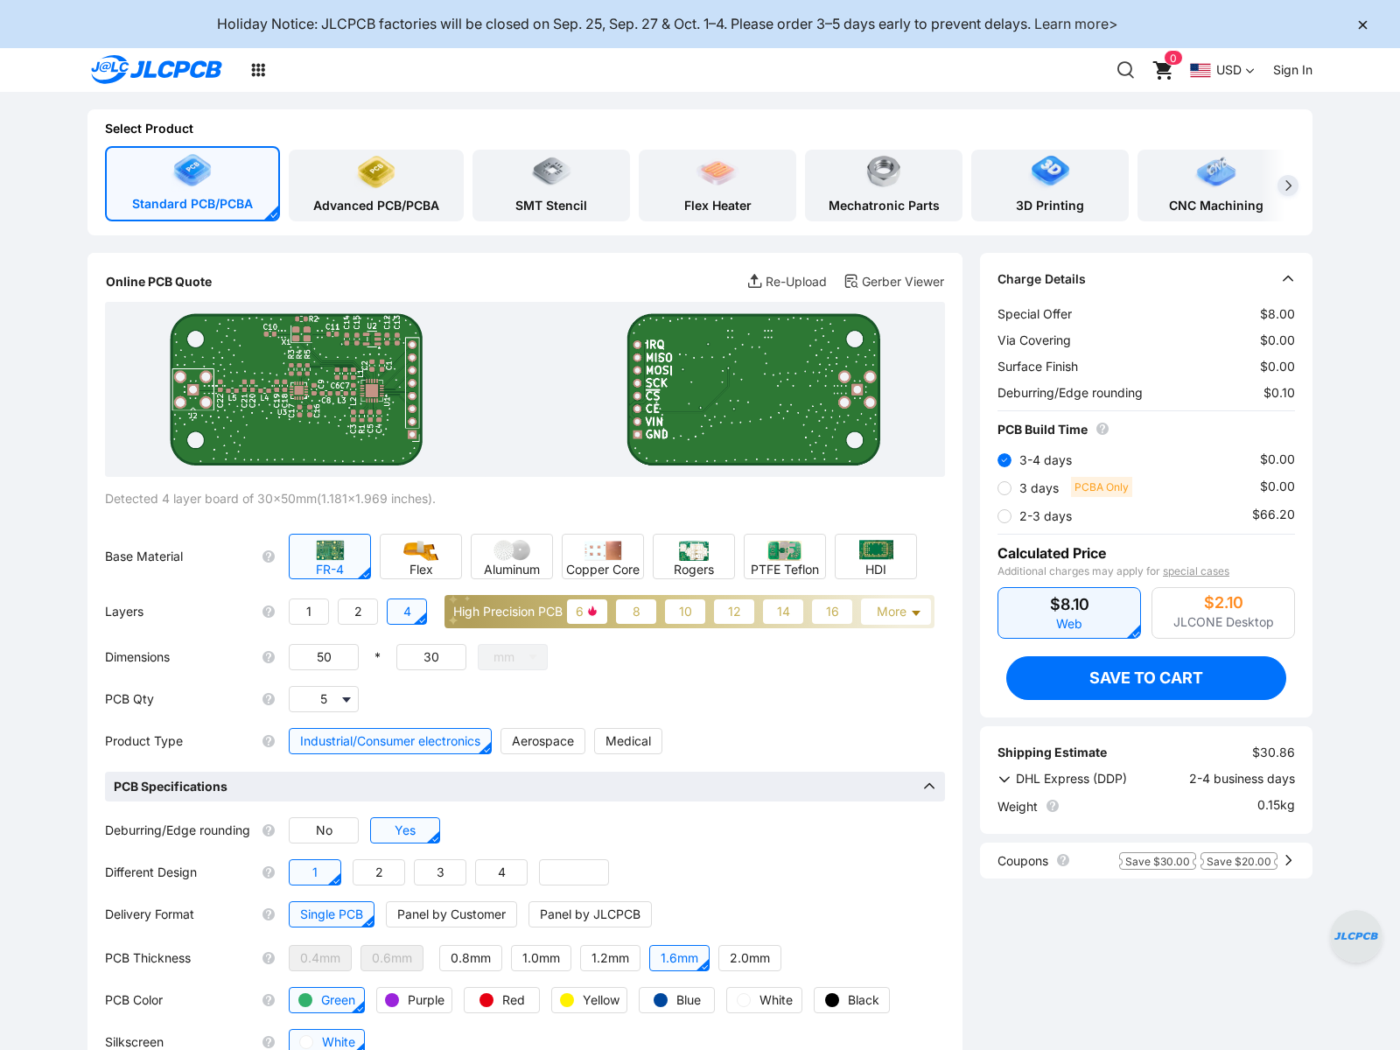
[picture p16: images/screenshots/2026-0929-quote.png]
The JLCPCB instant quote: 4 layer 30x50mm, 5 boards, $8.10 on the web tier and $2.10 on JLCONE


**Total time spent: 1 hour**

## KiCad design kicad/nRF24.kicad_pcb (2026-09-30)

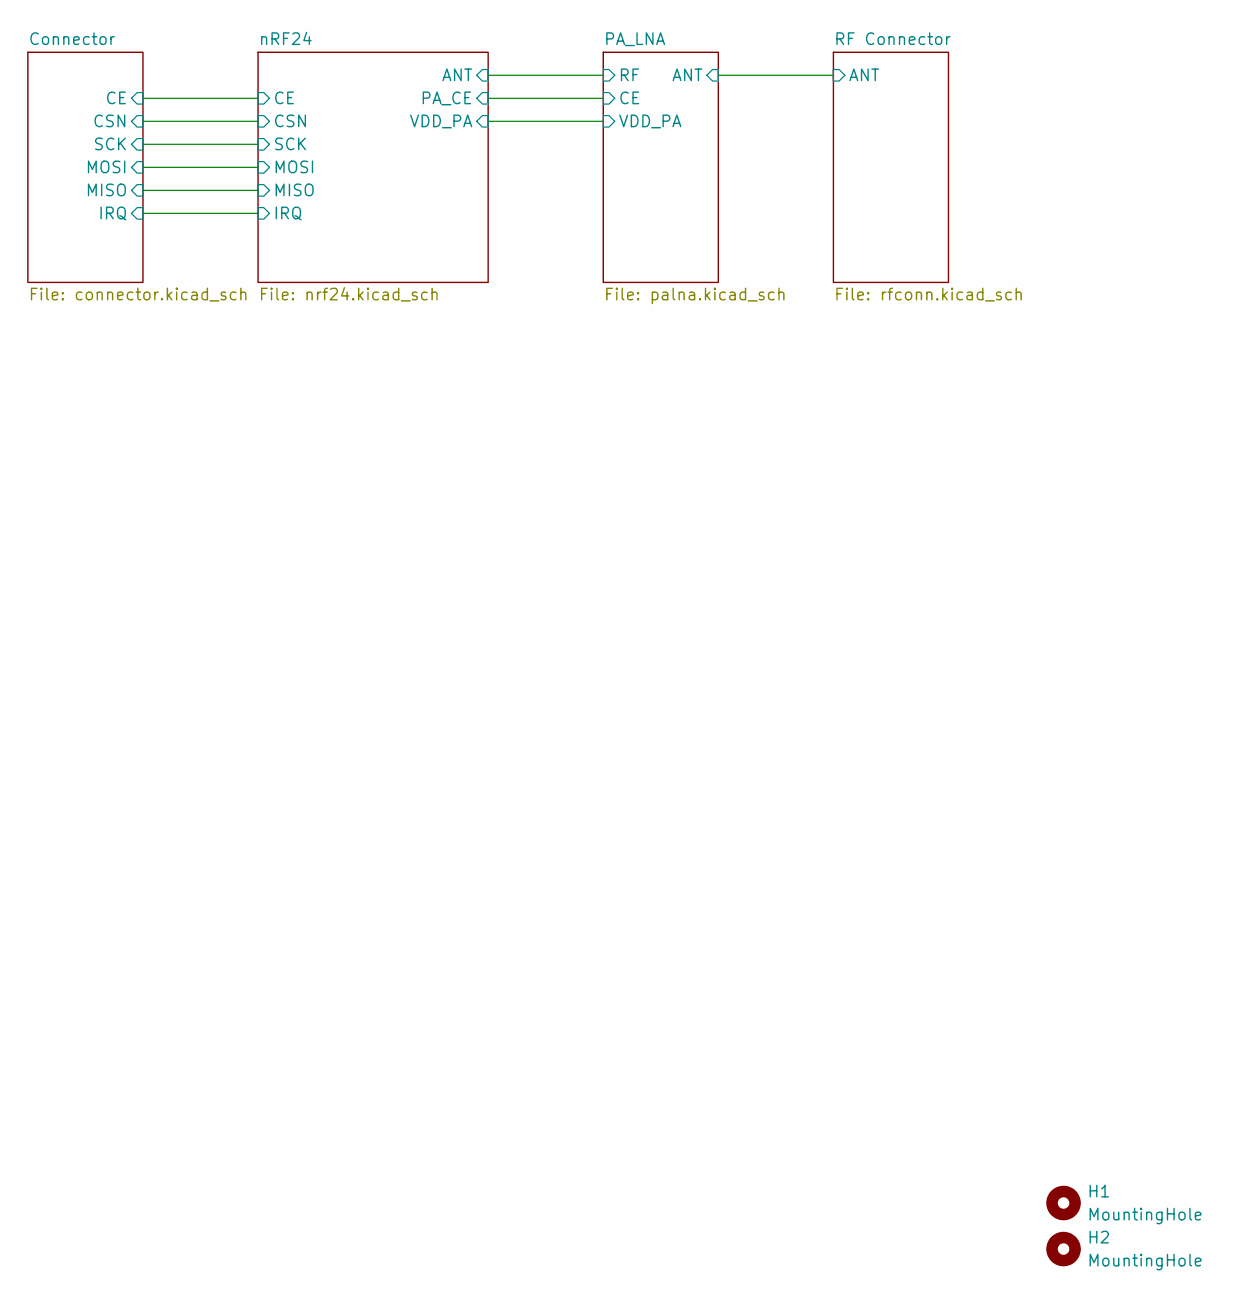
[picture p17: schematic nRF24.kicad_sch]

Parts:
H1, H2: MountingHole; MountingHole_3.2mm_M3

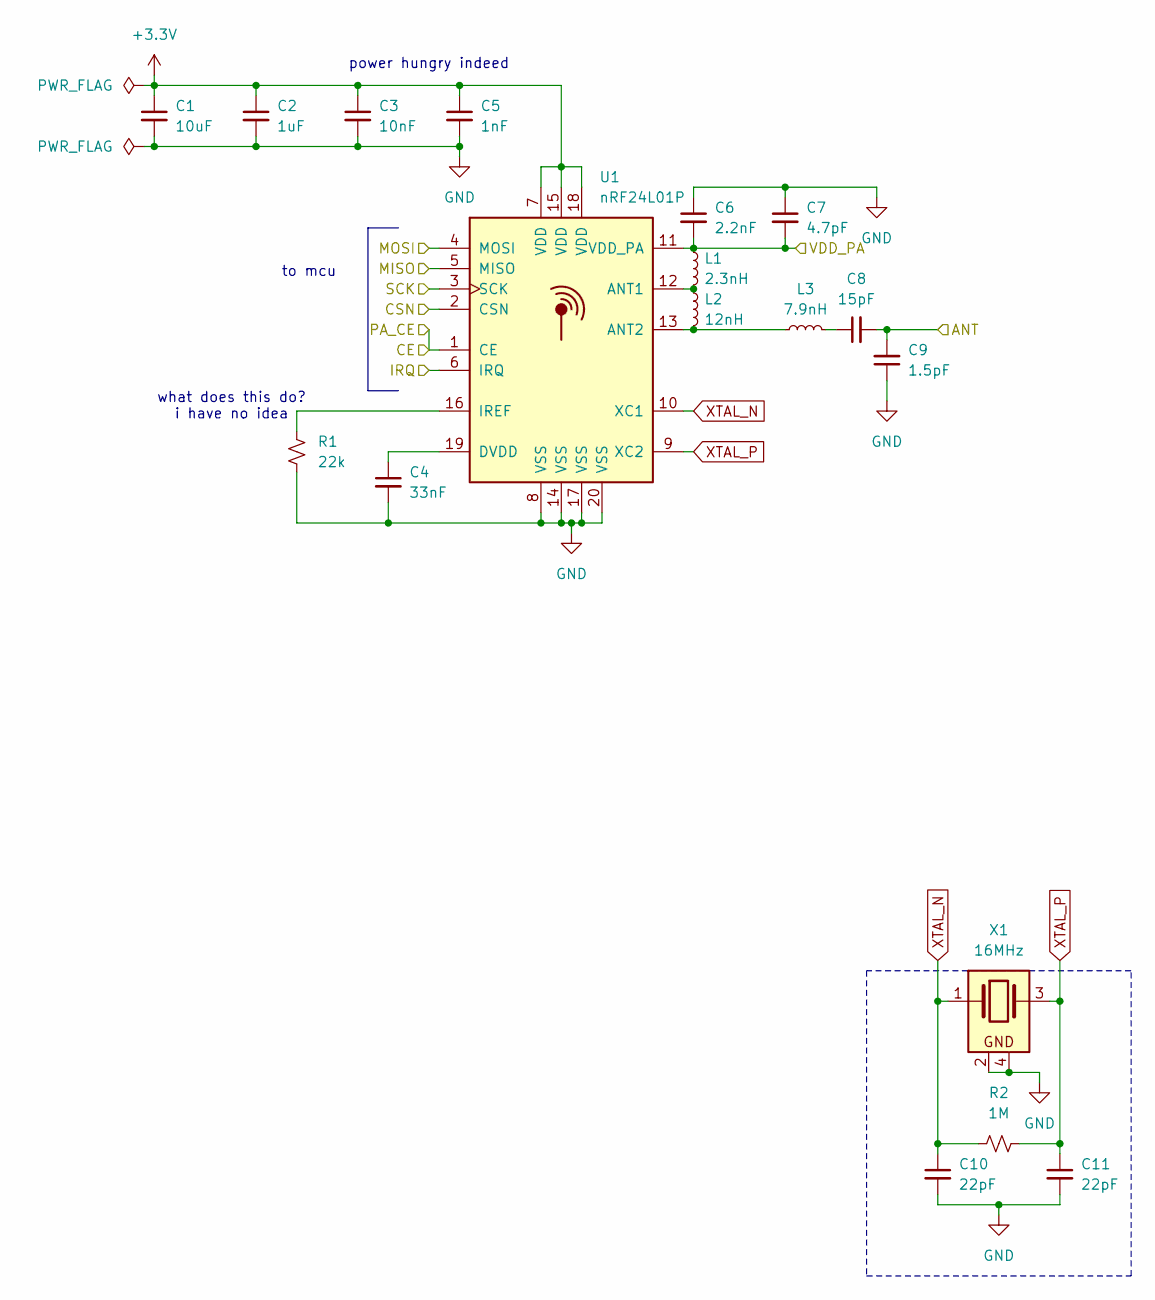
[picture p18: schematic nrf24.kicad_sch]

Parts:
C1: 10uF; C_0603_1608Metric
C2: 1uF; C_0603_1608Metric
C3: 10nF; C_0603_1608Metric
C4: 33nF; C_0603_1608Metric
C5: 1nF; C_0603_1608Metric
C6: 2.2nF; C_0603_1608Metric
C7: 4.7pF; C_0603_1608Metric
C8: 15pF; C_0603_1608Metric
C9: 1.5pF; C_0603_1608Metric
C10, C11: 22pF; C_0603_1608Metric
L1: 2.3nH; L_0402_1005Metric
L2: 12nH; L_0603_1608Metric
L3: 7.9nH; L_0402_1005Metric
R1: 22k; R_0603_1608Metric
R2: 1M; R_0603_1608Metric
U1: nRF24L01P; QFN-20-1EP_4x4mm_P0.5mm_EP2.5x2.5mm
X1: 16MHz; Crystal_SMD_3225-4Pin_3.2x2.5mm

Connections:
+3.3V: C1.1, C2.1, C3.1, C5.1, U1.7 (VDD), U1.15 (VDD), U1.18 (VDD); also elsewhere on the board
/Connector/CE: U1.1 (CE); also elsewhere on the board
/Connector/CSN: U1.2 (CSN); also elsewhere on the board
/Connector/IRQ: U1.6 (IRQ); also elsewhere on the board
/Connector/MISO: U1.5 (MISO); also elsewhere on the board
/Connector/MOSI: U1.4 (MOSI); also elsewhere on the board
/Connector/SCK: U1.3 (SCK); also elsewhere on the board
/PA_LNA/RF: C8.2, C9.2; also elsewhere on the board
/PA_LNA/VDD_PA: C6.2, C7.2, L1.1, U1.11 (VDD_PA); also elsewhere on the board
GND: C1.2, C2.2, C3.2, C4.2, C5.2, C6.1, C7.1, C9.1, C10.2, C11.2, R1.2, U1.8 (VSS), U1.14 (VSS), U1.17 (VSS), U1.20 (VSS), X1.2, X1.4; also elsewhere on the board
unnamed: C8.1, L3.2
unnamed: L1.2, L2.1, U1.12 (ANT1)
unnamed: L2.2, L3.1, U1.13 (ANT2)
unnamed: C4.1, U1.19 (DVDD)
unnamed: R1.1, U1.16 (IREF)
XTAL_N: C10.1, R2.1, U1.10 (XC1), X1.1
XTAL_P: C11.1, R2.2, U1.9 (XC2), X1.3

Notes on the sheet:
power hungry indeed
to mcu
what does this do? i have no idea

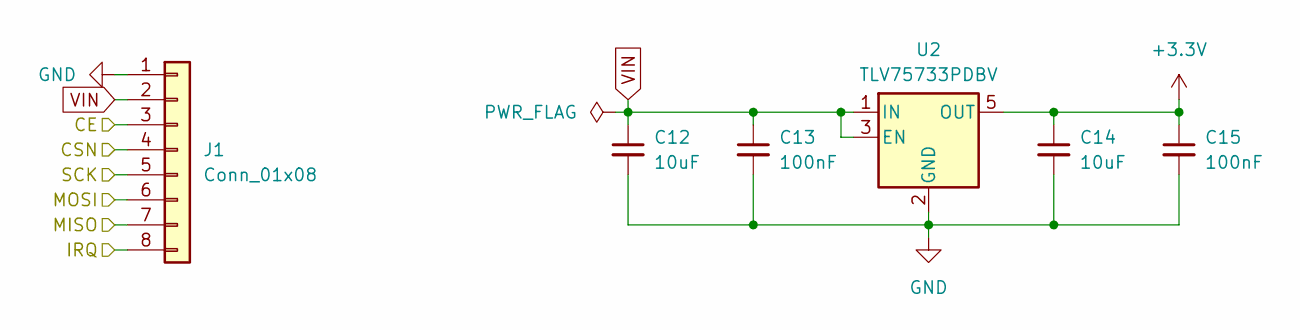
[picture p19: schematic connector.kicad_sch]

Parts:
C12, C14: 10uF; C_0603_1608Metric
C13, C15: 100nF; C_0603_1608Metric
J1: Conn_01x08; PinHeader_1x08_P2.54mm_Vertical
U2: TLV75733PDBV; SOT-23-5

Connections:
+3.3V: C14.1, C15.1, U2.5 (OUT); also elsewhere on the board
/Connector/CE: J1.3; also elsewhere on the board
/Connector/CSN: J1.4; also elsewhere on the board
/Connector/IRQ: J1.8; also elsewhere on the board
/Connector/MISO: J1.7; also elsewhere on the board
/Connector/MOSI: J1.6; also elsewhere on the board
/Connector/SCK: J1.5; also elsewhere on the board
GND: C12.2, C13.2, C14.2, C15.2, J1.1, U2.2 (GND); also elsewhere on the board
VIN: C12.1, C13.1, J1.2, U2.1 (IN), U2.3 (EN)

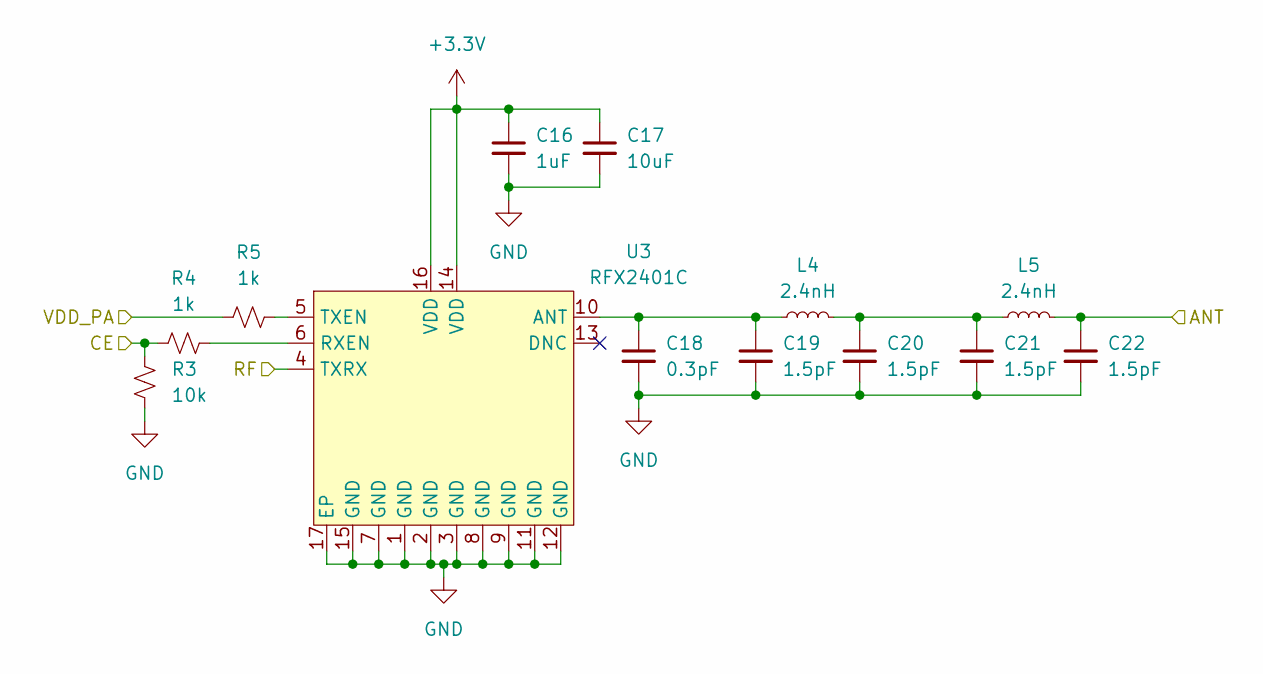
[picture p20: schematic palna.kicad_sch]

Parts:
C16: 1uF; C_0603_1608Metric
C17: 10uF; C_0603_1608Metric
C18: 0.3pF; C_0603_1608Metric
C19, C20, C21, C22: 1.5pF; C_0603_1608Metric
L4, L5: 2.4nH; L_0603_1608Metric
R3: 10k; R_0603_1608Metric
R4, R5: 1k; R_0603_1608Metric
U3: RFX2401C; QFN-16_L3.0-W3.0-P0.50-BL-EP1.7; LCSC C19213

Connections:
+3.3V: C16.1, C17.1, U3.14 (VDD), U3.16 (VDD); also elsewhere on the board
/Connector/CE: R3.2, R4.1; also elsewhere on the board
/PA_LNA/ANT: C22.1, L5.2; also elsewhere on the board
/PA_LNA/RF: U3.4 (TXRX); also elsewhere on the board
/PA_LNA/VDD_PA: R5.1; also elsewhere on the board
GND: C16.2, C17.2, C18.2, C19.2, C20.2, C21.2, C22.2, R3.1, U3.1 (GND), U3.2 (GND), U3.3 (GND), U3.7 (GND), U3.8 (GND), U3.9 (GND), U3.11 (GND), U3.12 (GND), U3.15 (GND), U3.17 (EP); also elsewhere on the board
unnamed: C20.1, C21.1, L4.2, L5.1
unnamed: C18.1, C19.1, L4.1, U3.10 (ANT)
unnamed: R4.2, U3.6 (RXEN)
unnamed: R5.2, U3.5 (TXEN)

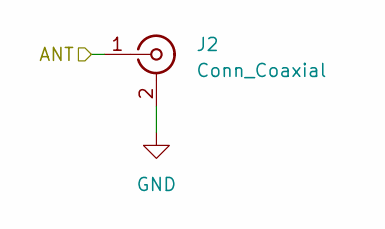
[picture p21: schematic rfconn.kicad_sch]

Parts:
J2: Conn_Coaxial; SMA_Amphenol_901-143_Horizontal

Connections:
/PA_LNA/ANT: J2.1 (In); also elsewhere on the board
GND: J2.2 (Ext); also elsewhere on the board

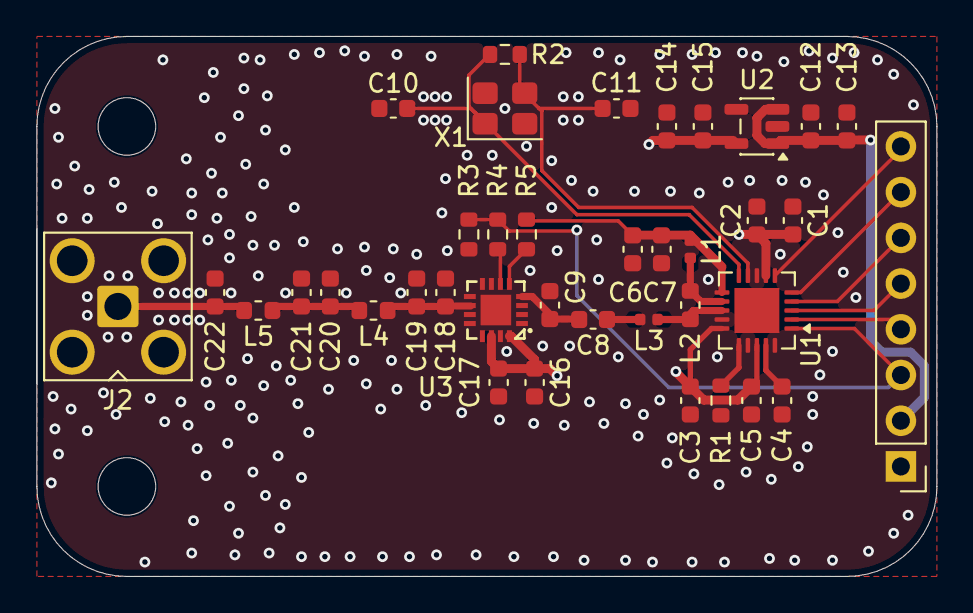
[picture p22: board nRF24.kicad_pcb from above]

Board: 4 copper layers, 50.0 x 30.0 mm, 40 parts (0 on the bottom side), 23 nets.

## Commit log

2026-09-22 readme and journal
    [connector.kicad_sch, nrf24.kicad_sch]
2026-09-22 journal and image
    [connector.kicad_sch, nRF24.kicad_sch, nrf24.kicad_sch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]
2026-09-25 add rfx2401c
    [RFX2401C.step, connector.kicad_sch, nRF24.kicad_pcb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]
2026-09-27 change crystal footprint
    [connector.kicad_sch, nRF24.kicad_pcb, nrf24.kicad_sch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]
2026-09-27 new gerbers
    [bom.csv, nRF24.kicad_pcb]
2026-09-27 add license
    [temp-freerouting.dsn]
2026-09-28 add graph
    [nRF24.kicad_pcb]
2026-09-30 journal images and reamde
    [BOM.csv, nRF24.kicad_pcb, nrf24.kicad_sch]
